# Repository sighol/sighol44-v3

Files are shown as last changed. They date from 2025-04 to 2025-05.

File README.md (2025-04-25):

# Sighol-44 v3

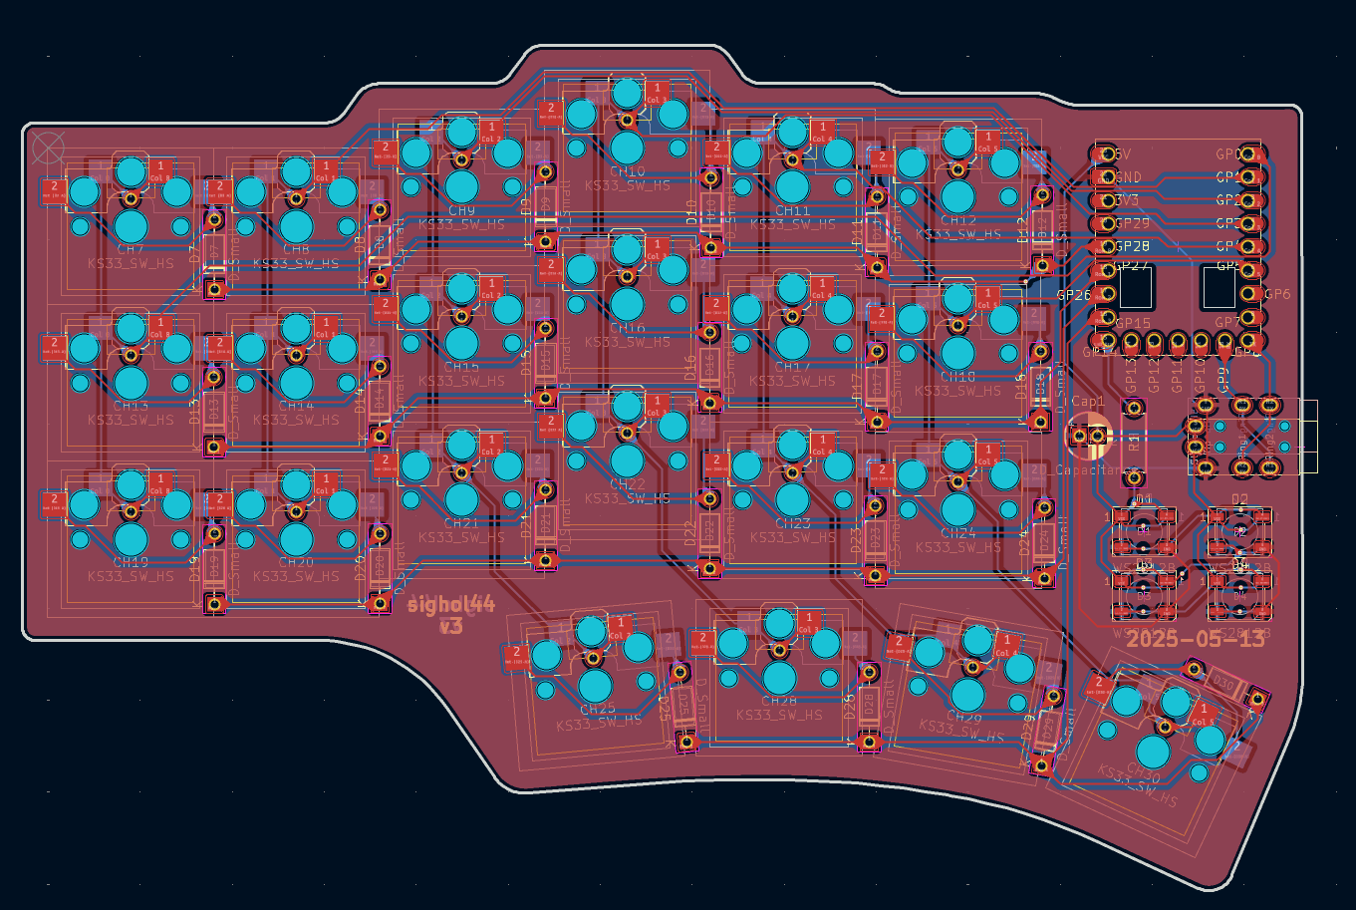
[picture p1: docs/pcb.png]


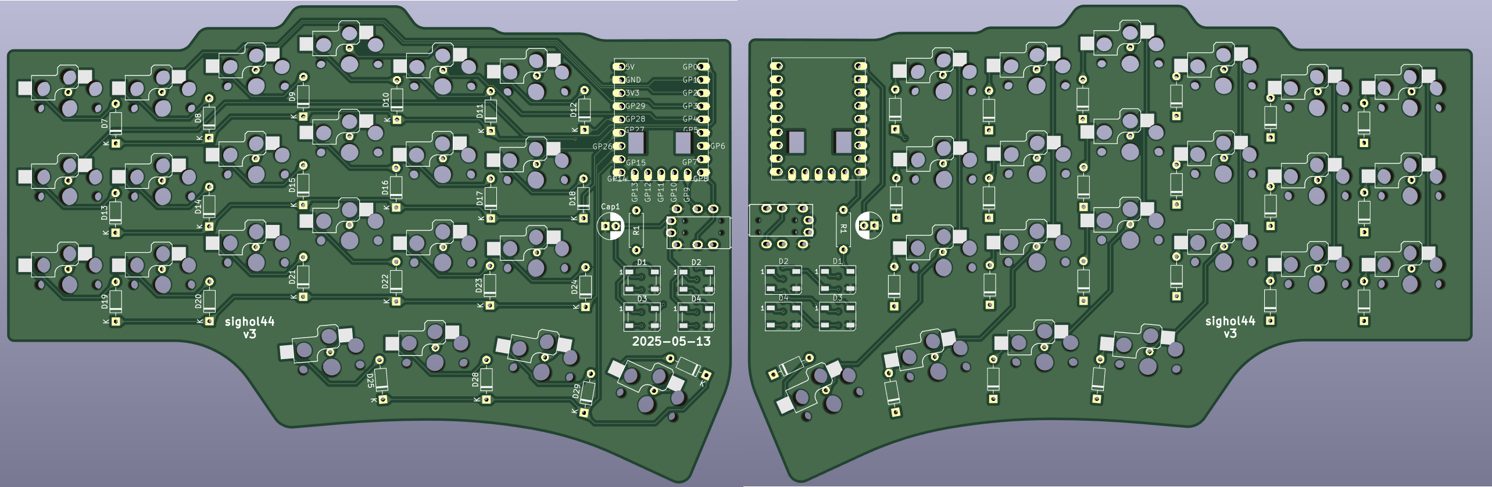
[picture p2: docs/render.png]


# Installation

Install both `kicad` and `kicad-library` from the OS package repository.

Remember to add the [marbastlib](https://github.com/ebastler/marbastlib) symbol and footprints library.
Check the github page for installation instructions.

Also install the `Fabrication toolkit` from the official KiCad repository.
Search for `JLC` in the plugins tab.

# Inkscape edge cut tutorial

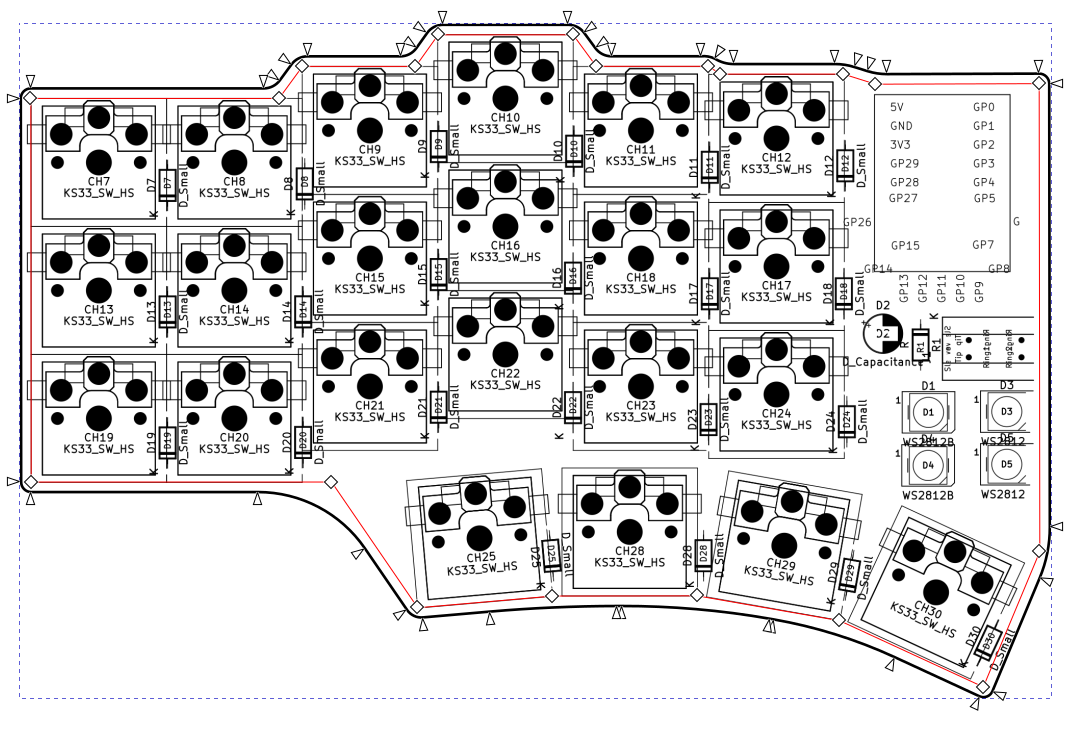
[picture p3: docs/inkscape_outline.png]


## Export SVG from KiCad
- In KiCad, *File* -> *Print*
- Select the Fab, Silkscreen, and User.Drawings layers.
- Then print as SVG

## Convert SVG to Bitmap to make it easier to work with. (optional)
- Open the SVG in inkscape.
- Open Edit ->, Preference, and select the *Imported Images* tab.
- Change the Craete resolution to about 500 dpi and close the preferences window.
- Then select (S) the white background and delete it.
- Then select (S) everything else.
- Click on Edit -> Make a Bitmap copy.
- Then move the bitmap copy to the center of the screen and delete all the other paths

Another alternative is to create a new layer, and move all the paths into this layer.
Snapping will work better when drawing the initial bezier curve, but I don't think it is worth it.

## Draw outline

- Use the **Pen Tool** (B) to draw an outline around the board. Use straight lines.b
- Hold down CTRL to draw straight lines.
- Move around the canvas by holding down the middle mouse button.
- After you have completed the outline, you can use the Node Tool (N) to delete nodes that are redundant. Select the node and use the **Delete** key.
- Delete bezier curve handles by holding control and left clicking on them.
- Add bezier curve handles by holding control and left clicking on a node.
- Double click on the curve to add a new node.
- Show the bezier handles by toggling a button to the right of the X and Y text boxes.
- The X and Y text boxes can also be used to place the nodes.

## Path effects
- Make sure none of the nodes have bezier curve handles.
- First create an offset of around 1mm.
- Then create a corner of around 1mm.
- Then you can customize the corners using the Node Tool (N).
- Make sure the radiuses you customize are symmetric and equal. You _will_ notice.
- For the thumb keys, it is best to have the biggest possible radius (to the center of the switch).

## Exporting SVG for KiCad

- File -> Export (Ctrl+Shift+E)
- Select the output directory and file. Should be `output_export.svg`.
- Toggle **Export Selected Only**.
- Select the outline (S).
- Click on the **Export** button.

## Import into KiCad

- File -> Import -> Graphics
- Use Import scale 1.33 and set layer to Edge.Cuts, and click OK.
- It is useful to select the outline and press M to move it around using the arrow keys. Press ENTER to confirm.
- You will have to iterate. If you create a big fill zone (select F.Cu and fill with ground), and then fill with **B**, you can use that as a guide when deleting and adding back the new edge cut.
- Alternatively, after placing it, notice

It is easy to place the new export on the of the previous export and then delete the previous, for placement.

## Tips and tricks with design

- The bigger the outline, the easier it will be to place rubber feet so that it doesn't wobble.
- Place the grid on the top-left key. `Place` -> `Grid`.
- Guideline: Horizontal traces are blue. Vertical traces are red.
- In **PCB Editor**:
    - F8 to apply from schematics
    - B to build fill zones.
    - Ctrl+Shift+F to import graphics.
    - Top Copper **PgUp**
    - Bottom Copper **PgDown**
    - V: Toggle top and bottom copper layer
    - Tools -> Update Footprints from Library: Take them all!
    - Text fields support [variables substitiution](https://docs.kicad.org/master/id/eeschema/eeschema_advanced.html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,schematic%20or%20board%20setup%20dialogs.)
    - D: Drag component line or track. (You can also drag the tracks.)
    - G: Drag component node or track.

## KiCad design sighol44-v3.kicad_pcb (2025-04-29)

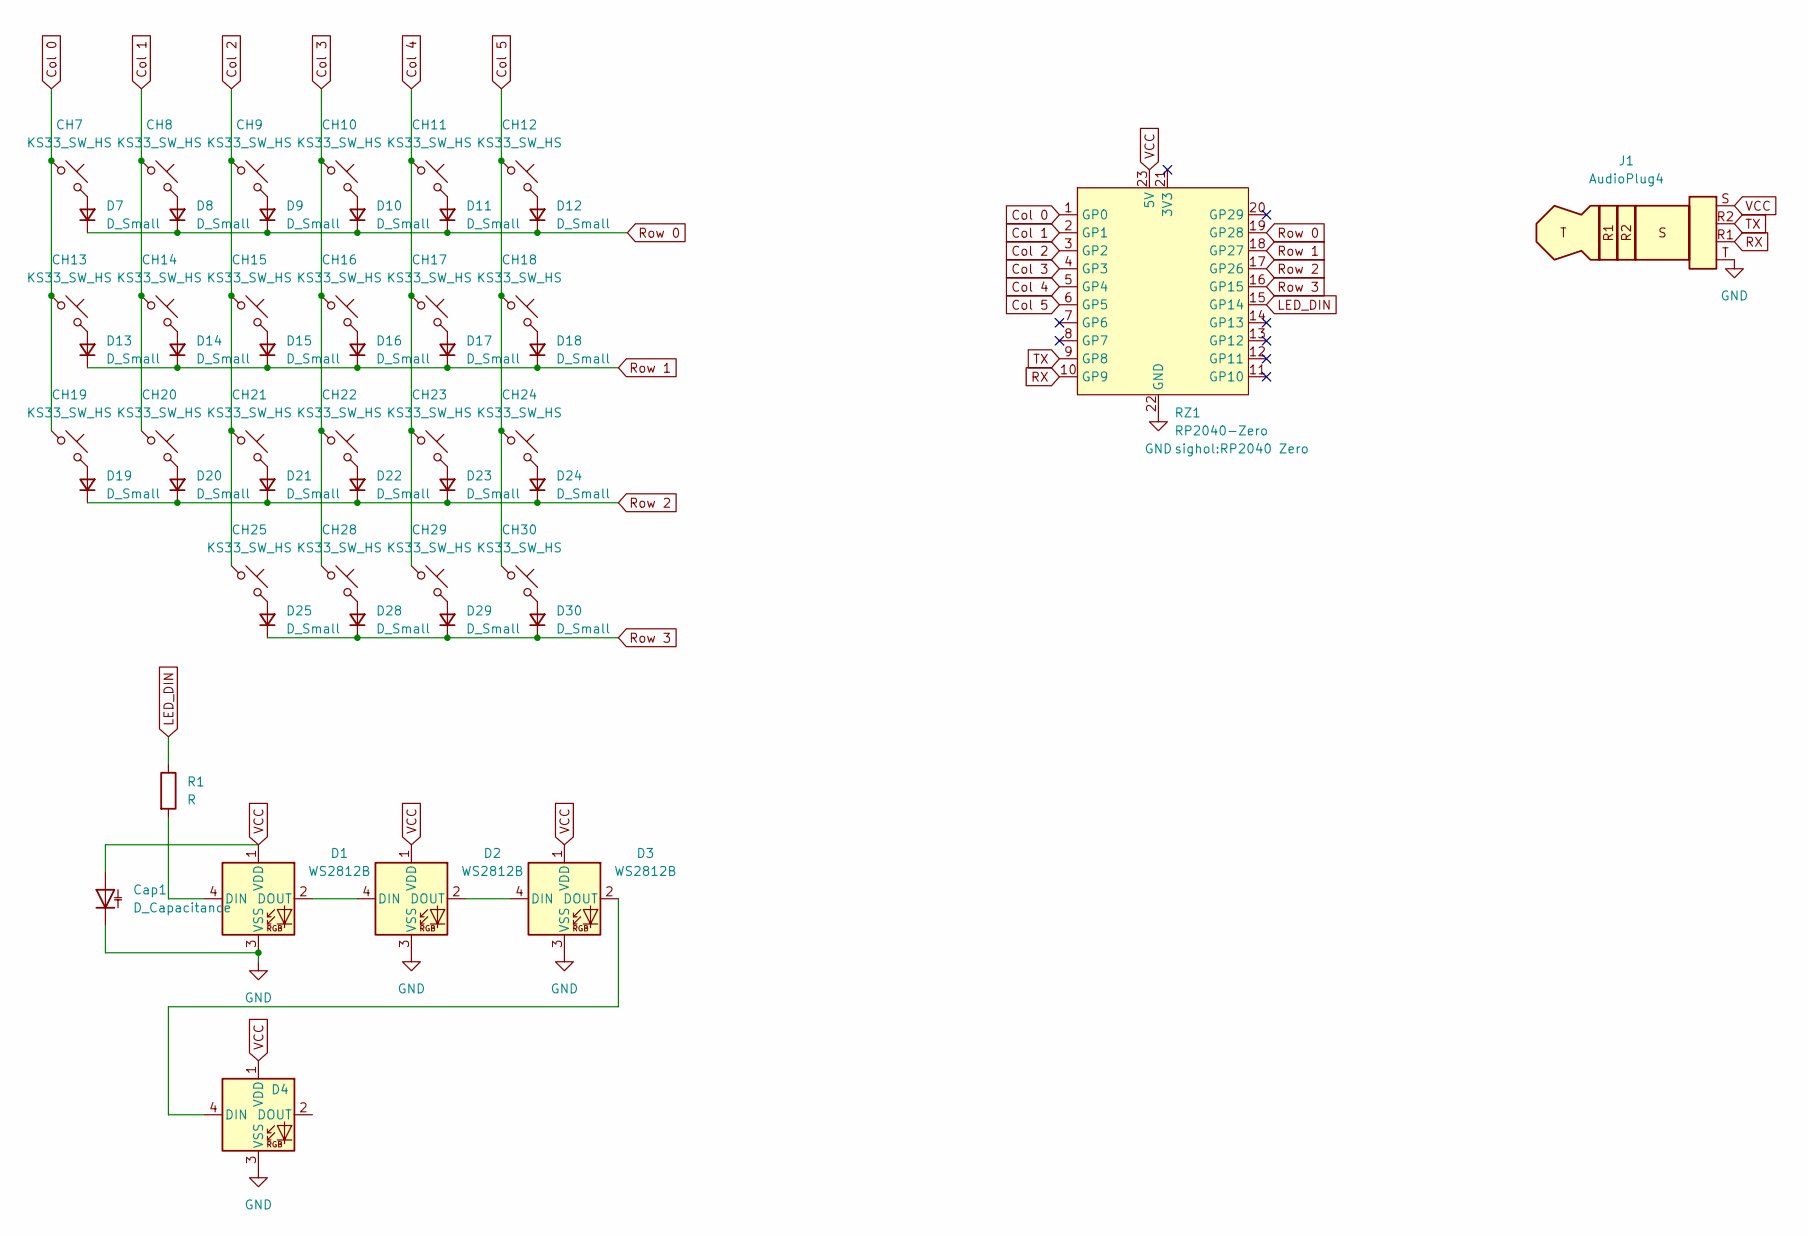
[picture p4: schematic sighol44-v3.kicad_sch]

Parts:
CH7, CH8, CH9, CH10, CH11, CH12, CH13, CH14, CH15, CH16, CH17, CH18, CH19, CH20, CH21, CH22, CH23, CH24, CH25, CH28, CH29, CH30: KS33_SW_HS; Kailh_socket_PG1350 reversible HS-only
Cap1: D_Capacitance; CP_Radial_D5.0mm_P2.00mm
D1, D2, D3, D4: WS2812B; LED_WS2812B_PLCC4_5.0x5.0mm_P3.2mm_reversible
D7, D8, D9, D10, D11, D12, D13, D14, D15, D16, D17, D18, D19, D20, D21, D22, D23, D24, D25, D28, D29, D30: D_Small; D_DO-35_SOD27_P7.62mm_Horizontal
J1: AudioPlug4; TRRS-PJ-320A
R1: R; R_Axial_DIN0207_L6.3mm_D2.5mm_P7.62mm_Horizontal
RZ1: RP2040-Zero; RP2040 Zero

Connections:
Col 0: CH7.1, CH13.1, CH19.1, RZ1.1 (GP0)
Col 1: CH8.1, CH14.1, CH20.1, RZ1.2 (GP1)
Col 2: CH9.1, CH15.1, CH21.1, CH25.1, RZ1.3 (GP2)
Col 3: CH10.1, CH16.1, CH22.1, CH28.1, RZ1.4 (GP3)
Col 4: CH11.1, CH17.1, CH23.1, CH29.1, RZ1.5 (GP4)
Col 5: CH12.1, CH18.1, CH24.1, CH30.1, RZ1.6 (GP5)
GND: Cap1.1 (K), D1.3 (VSS), D2.3 (VSS), D3.3 (VSS), D4.3 (VSS), J1.T, RZ1.22 (GND)
LED_DIN: R1.1, RZ1.15 (GP14)
unnamed: D1.4 (DIN), R1.2
unnamed: D1.2 (DOUT), D2.4 (DIN)
unnamed: D2.2 (DOUT), D3.4 (DIN)
unnamed: D3.2 (DOUT), D4.4 (DIN)
unnamed: CH7.2, D7.2 (A)
unnamed: CH8.2, D8.2 (A)
unnamed: CH9.2, D9.2 (A)
unnamed: CH10.2, D10.2 (A)
unnamed: CH11.2, D11.2 (A)
unnamed: CH12.2, D12.2 (A)
unnamed: CH13.2, D13.2 (A)
unnamed: CH14.2, D14.2 (A)
unnamed: CH15.2, D15.2 (A)
unnamed: CH16.2, D16.2 (A)
unnamed: CH17.2, D17.2 (A)
unnamed: CH18.2, D18.2 (A)
unnamed: CH19.2, D19.2 (A)
unnamed: CH20.2, D20.2 (A)
unnamed: CH21.2, D21.2 (A)
unnamed: CH22.2, D22.2 (A)
unnamed: CH23.2, D23.2 (A)
unnamed: CH24.2, D24.2 (A)
unnamed: CH25.2, D25.2 (A)
unnamed: CH28.2, D28.2 (A)
unnamed: CH29.2, D29.2 (A)
unnamed: CH30.2, D30.2 (A)
RX: J1.R1, RZ1.10 (GP9)
Row 0: D7.1 (K), D8.1 (K), D9.1 (K), D10.1 (K), D11.1 (K), D12.1 (K), RZ1.19 (GP28)
Row 1: D13.1 (K), D14.1 (K), D15.1 (K), D16.1 (K), D17.1 (K), D18.1 (K), RZ1.18 (GP27)
Row 2: D19.1 (K), D20.1 (K), D21.1 (K), D22.1 (K), D23.1 (K), D24.1 (K), RZ1.17 (GP26)
Row 3: D25.1 (K), D28.1 (K), D29.1 (K), D30.1 (K), RZ1.16 (GP15)
TX: J1.R2, RZ1.9 (GP8)
VCC: Cap1.2 (A), D1.1 (VDD), D2.1 (VDD), D3.1 (VDD), D4.1 (VDD), J1.S, RZ1.23 (5V)

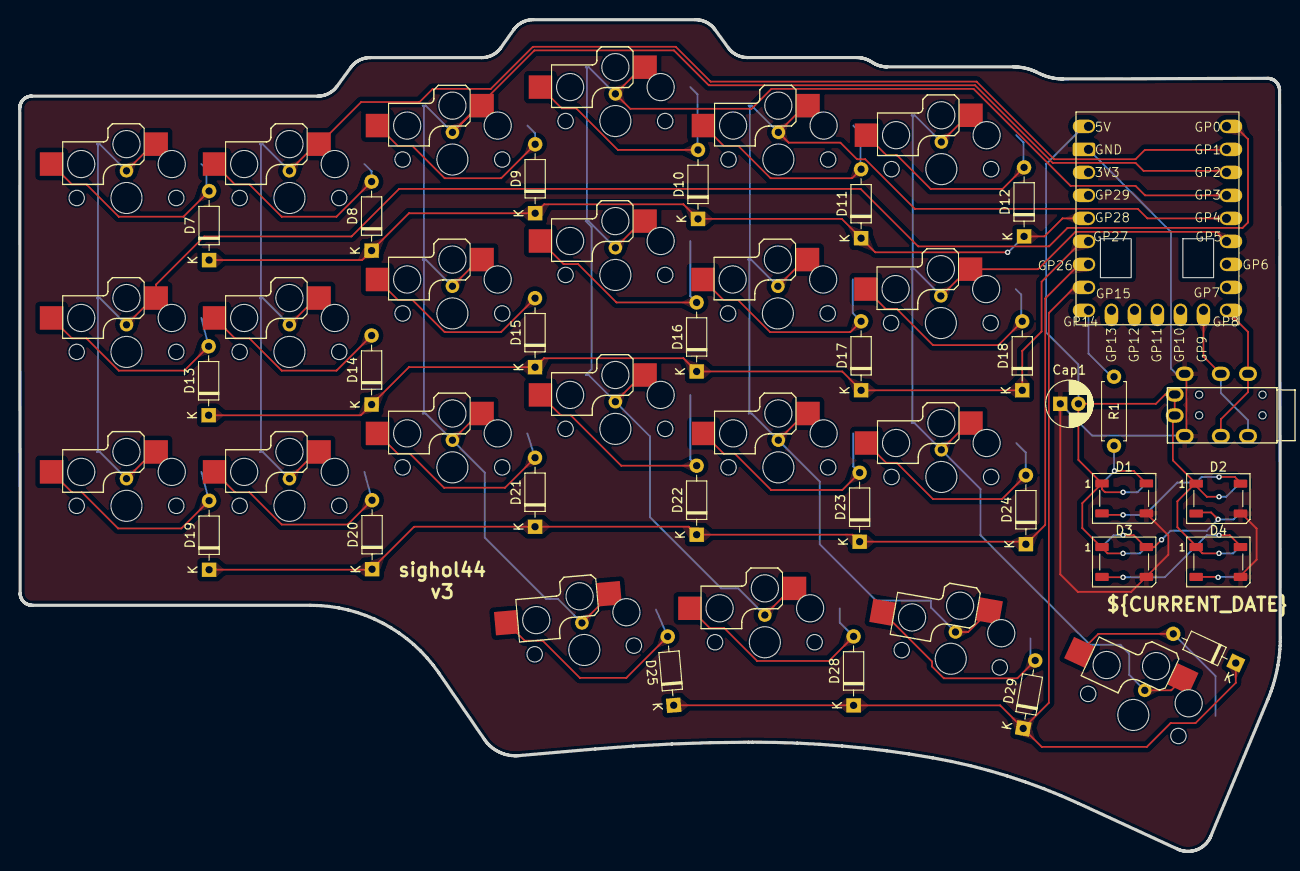
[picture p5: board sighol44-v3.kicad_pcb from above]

Board: 2 copper layers, 139.2 x 91.9 mm, 52 parts (0 on the bottom side), 41 nets.

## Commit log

2025-04-25 Add edge cut and add tutorial to README
    [sighol-split.kicad_pcb]
2025-04-25 Thicker outline and more traces
    [sighol-split.kicad_pcb]
2025-04-25 Complete most traces (not LEDs)
    [sighol-split.kicad_pcb]
2025-04-25 pcb in readme
2025-04-25 Try to fix LEDs. All checks succeed
    [sighol-split.kicad_pcb]
2025-04-25 Updatte RP2040 Zero footprint with silkscreen border
    [sighol-split.kicad_pcb]
2025-04-25 LED footprint + current_date
    [sighol-split.kicad_pcb]
2025-04-25 render + paint capacitor on back silk
    [sighol-split.kicad_pcb, sighol-split.kicad_sch]
2025-04-25 Moved tracks around using D and G
    [sighol-split.kicad_pcb]
2025-04-25 Move traces around and make some footprints more pretty. Resistor is more pretty
    [sighol-split.kicad_pcb, sighol-split.kicad_sch]
2025-04-25 More track movements
    [sighol-split.kicad_pcb]
2025-04-26 Move some tracks around again
    [sighol-split.kicad_pcb]
2025-04-27 Move D30 diode so that a rubbe foot can be placed bottom right
    [sighol-split.kicad_pcb]
2025-04-28 Align LEDs
    [sighol-split.kicad_pcb]
2025-04-29 Rename to sighol44-v3
    [sighol44-v3.kicad_pcb, sighol44-v3.kicad_sch]
2025-04-29 Fat outline (2mm)
    [sighol44-v3.kicad_pcb]
2025-04-29 Remove circle and move some tracks
    [sighol44-v3.kicad_pcb]
2025-04-29 Remove GND Vias. Fill islands instead
    [sighol44-v3.kicad_pcb]
2025-04-29 Move bottom right diode + other minor changes
    [sighol44-v3.kicad_pcb]
2025-04-29 Ready for manufacturing
    [sighol44-v3.kicad_pcb, sighol44-v3.kicad_sch]
2026-02-17 Fix send_string_rewrite and add reviewable button
